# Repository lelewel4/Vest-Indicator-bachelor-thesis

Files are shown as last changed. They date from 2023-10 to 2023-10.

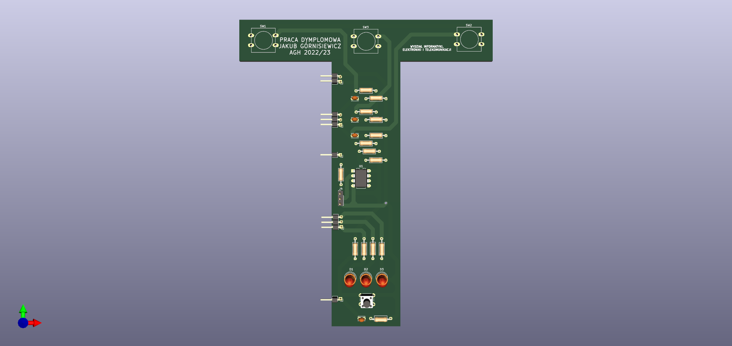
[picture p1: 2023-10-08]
PCB/Steering wheel/kierownica.png

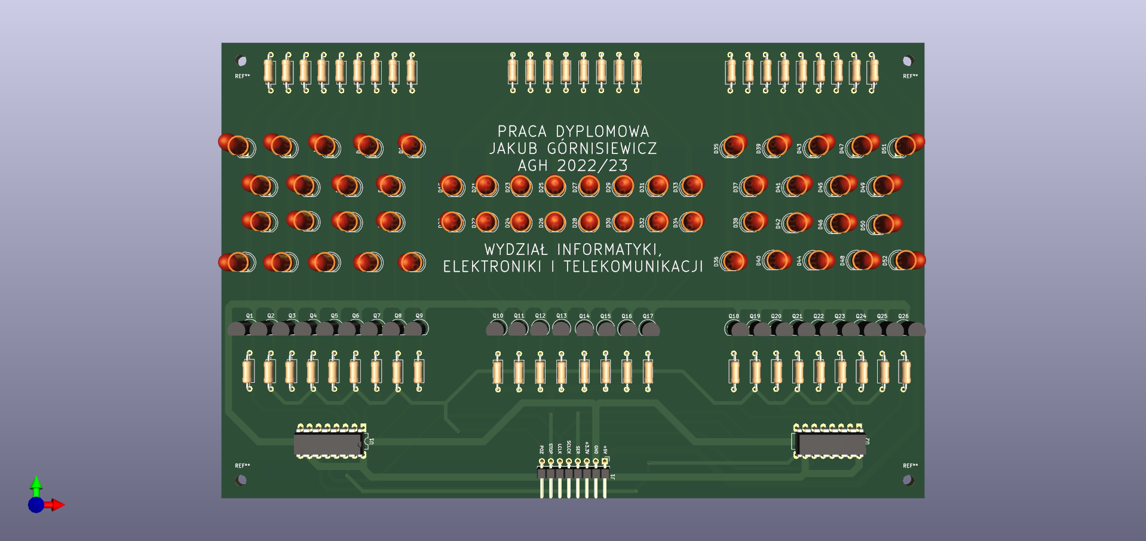
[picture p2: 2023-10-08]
PCB/Vest/kamizelka.png

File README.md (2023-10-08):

The engineering diploma thesis describes the design of a signal vest for an electric scooter driver based on wireless communication and STM32 microcontrollers.

The work contains a short introduction to the subject of e-scooters, after which the goal and scope of the project were defined. Existing commercial signal vest solutions were also reviewed. Then, the components enabling wireless communication were analyzed and development kits were selected. The entire project was divided into two parts: transmitting and receiving. Their appropriate functionality and requirements are outlined. Both parts discuss and justify the choice of specific electronic components. Electrical diagrams and printed circuits designed in KiCad are also presented. After this part, the PCBs were manufactured along with the assembly of elements. The subsections devoted to the software present the CubeMX environment, block diagrams, used libraries and interesting fragments of the source code written in C. Then, in the Tinkercad program, the appropriate housings were designed and manufactured in 3D technology. After assembling the project, functional tests were carried out.
The summary contains conclusions and further development directions for the project of a signaling vest for an electric scooter driver.

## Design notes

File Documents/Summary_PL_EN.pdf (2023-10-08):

W pracy inżynierskiej opisano projekt wykonanej kamizelki sygnalizacyjnej dla kierowcy hulajnogi elektrycznej w oparciu o komunikację bezprzewodową oraz mikrokontrolery STM32.

Praca zawiera krótki wstęp do tematyki e-hulajnóg, po którym określono cel i zakres projektu. Dokonano także przeglądu istniejących komercyjnych rozwiązań kamizelek sygnalizacyjnych. Następnie przeanalizowano komponenty umożliwiające komunikacje bezprzewodową oraz wybrano zestawy uruchomieniowe. Cały projekt podzielono na dwie części: nadawczą oraz odbiorczą. Nakreślono ich odpowiednią funkcjonalność oraz stawiane wymagania. W obu częściach omówiono i uzasadniono wybór konkretnych komponentów elektronicznych. Przedstawiono również zaprojektowane w programie KiCad schematy elektryczne oraz obwody drukowane. Po tej części dokonano wytworzenia płytek PCB wraz z montażem elementów. W podrozdziałach poświęconych oprogramowaniu zaprezentowano środowisko CubeMX, schematy blokowe, wykorzystane biblioteki oraz interesujące fragmenty kodu źródłowego napisanego w języku C. Następnie w programie Tinkercad zaprojektowano oraz wytworzono odpowiednie obudowy w technologii 3D. Po złożeniu projektu w całość przeprowadzono testy funkcjonalne.

W podsumowaniu zawarto wnioski oraz dalsze kierunki rozwoju projektu kamizelki sygnalizacyjnej dla kierowcy hulajnogi elektrycznej.

The engineering diploma thesis describes the design of a signal vest for an electric scooter driver based on wireless communication and STM32 microcontrollers.

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

The summary contains conclusions and further development directions for the project of a signaling vest for an electric scooter driver.

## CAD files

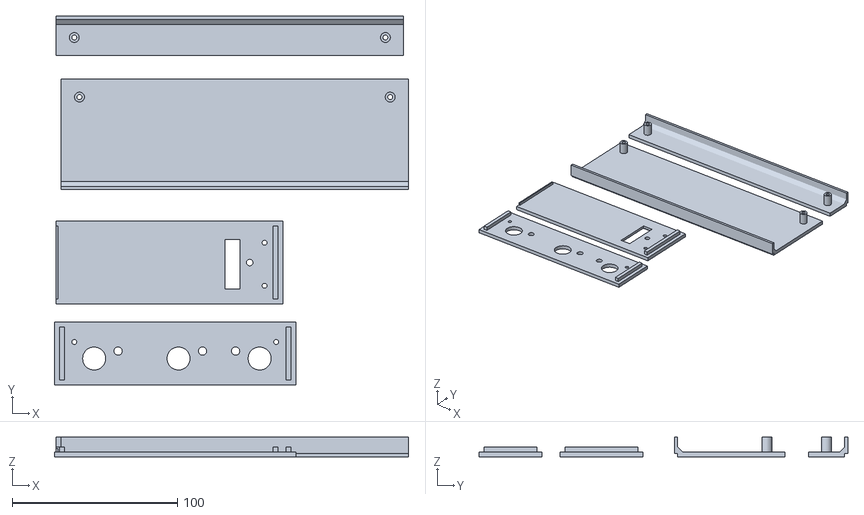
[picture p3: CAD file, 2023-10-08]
PRINT 3D/Fixing/tinker.obj
214.0 x 223.0 x 12.0

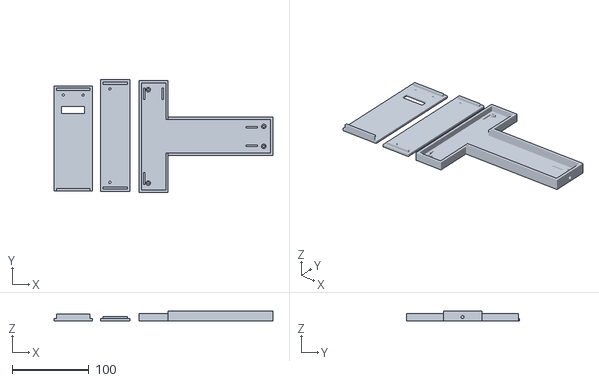
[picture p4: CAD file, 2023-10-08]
PRINT 3D/Steering wheel/Bottom and Top/tinker.obj
286.0 x 147.0 x 13.0

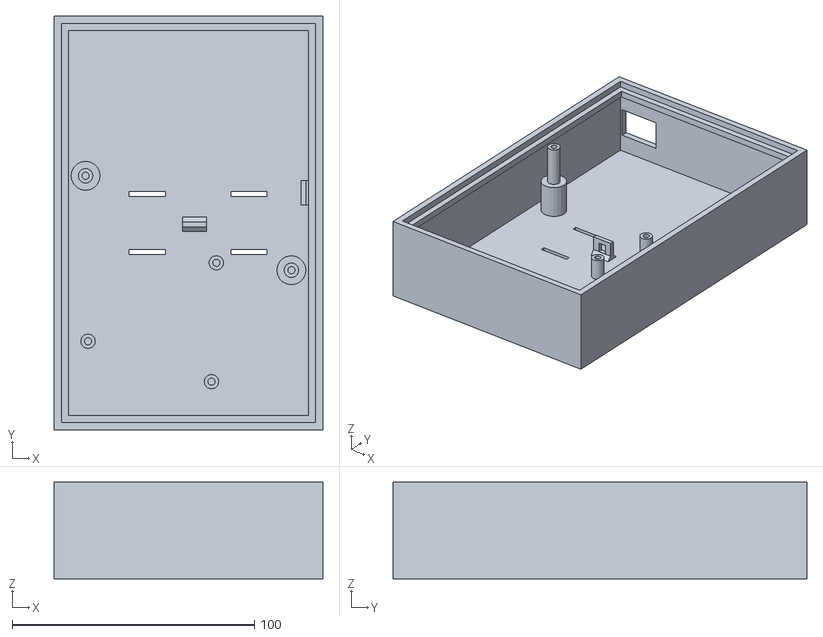
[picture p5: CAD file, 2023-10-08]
PRINT 3D/Supply/Bottom/tinker.obj
111.0 x 171.0 x 40.0

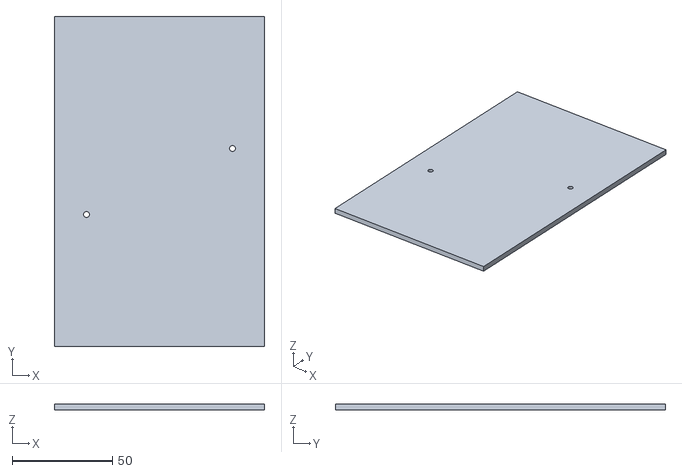
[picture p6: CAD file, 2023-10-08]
PRINT 3D/Supply/Top/tinker.obj
105.0 x 165.0 x 3.00

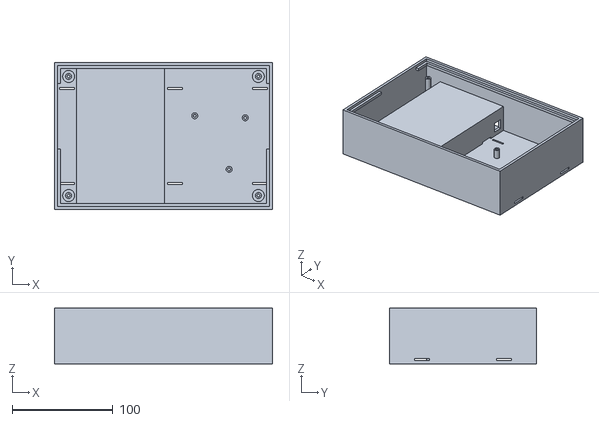
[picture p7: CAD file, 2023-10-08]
PRINT 3D/Vest/Bottom/tinker.obj
216.0 x 146.0 x 55.0

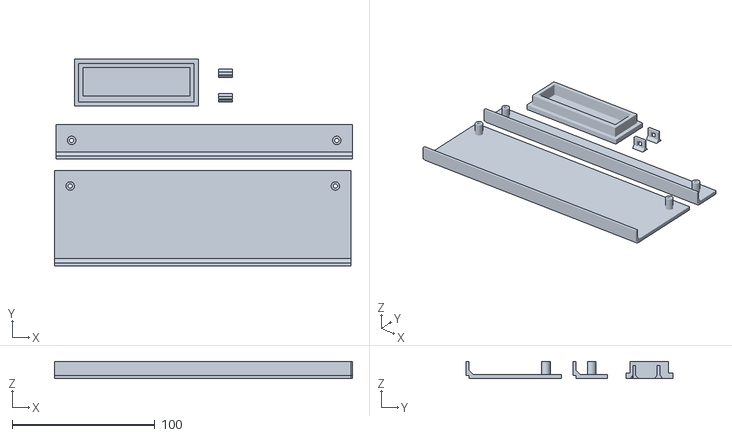
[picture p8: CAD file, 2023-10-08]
PRINT 3D/Vest/Top/tinker.obj
209.0 x 145.0 x 12.0

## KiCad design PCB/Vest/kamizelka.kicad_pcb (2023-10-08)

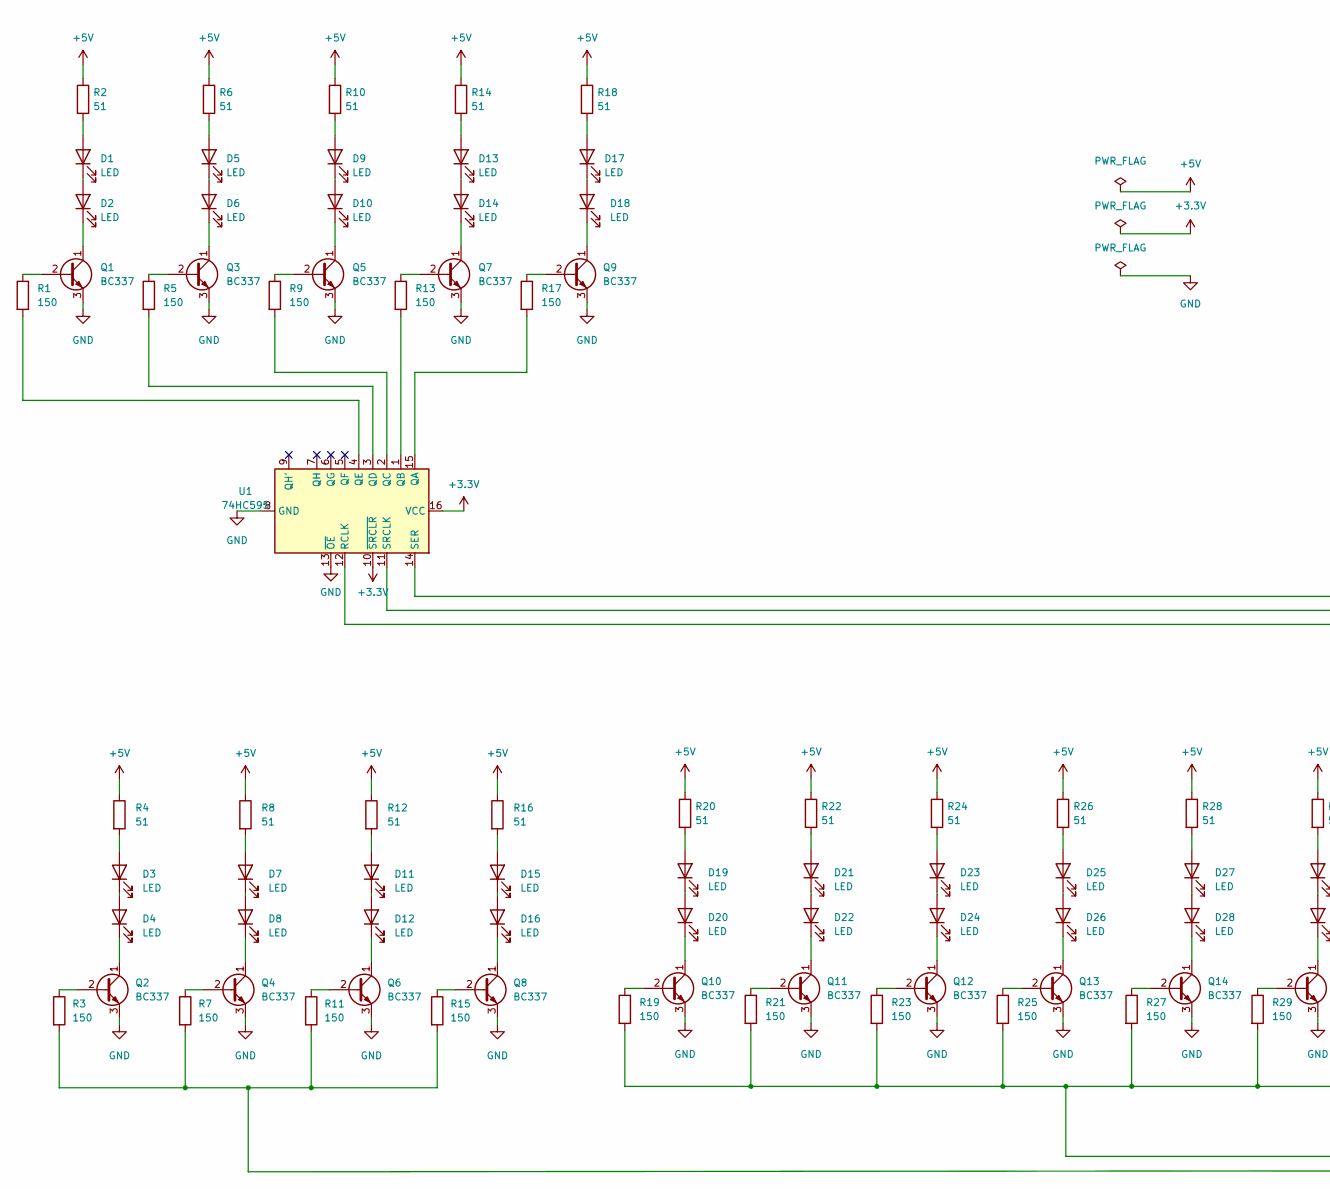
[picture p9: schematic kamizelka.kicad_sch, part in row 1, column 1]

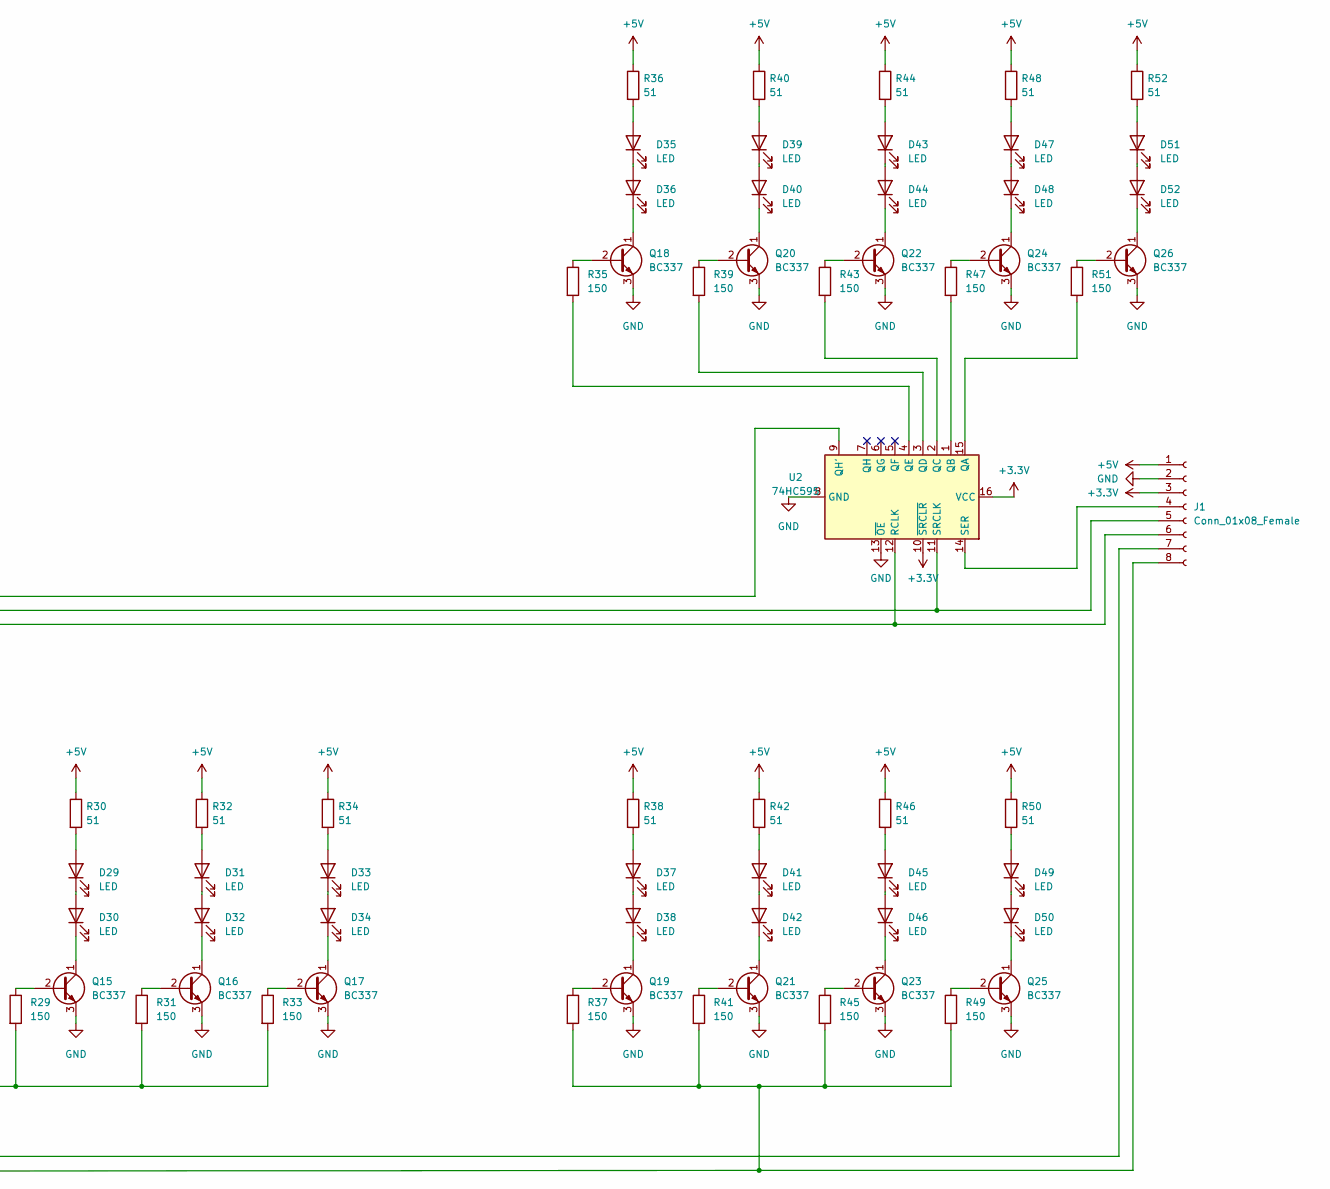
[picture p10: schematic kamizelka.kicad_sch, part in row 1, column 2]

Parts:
D1, D2, D3, D4, D5, D6, D7, D8, D9, D10, D11, D12, D13, D14, D15, D16, D17, D18, D19, D20, D21, D22, D23, D24, D25, D26, D27, D28, D29, D30, D31, D32, D33, D34, D35, D36, D37, D38, D39, D40, D41, D42, D43, D44, D45, D46, D47, D48, D49, D50, D51, D52: LED; LED_D5.0mm
J1: Conn_01x08_Female; PinHeader_1x08_P2.54mm_Horizontal
Q1, Q2, Q3, Q4, Q5, Q6, Q7, Q8, Q9, Q10, Q11, Q12, Q13, Q14, Q15, Q16, Q17, Q18, Q19, Q20, Q21, Q22, Q23, Q24, Q25, Q26: BC337; TO-92_Inline
R1, R3, R5, R7, R9, R11, R13, R15, R17, R19, R21, R23, R25, R27, R29, R31, R33, R35, R37, R39, R41, R43, R45, R47, R49, R51: 150; R_Axial_DIN0207_L6.3mm_D2.5mm_P10.16mm_Horizontal
R2, R4, R6, R8, R10, R12, R14, R16, R18, R20, R22, R24, R26, R28, R30, R32, R34, R36, R38, R40, R42, R44, R46, R48, R50, R52: 51; R_Axial_DIN0207_L6.3mm_D2.5mm_P10.16mm_Horizontal
U1, U2: 74HC595; DIP-16_W7.62mm_LongPads

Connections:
+3V3: J1.3, U1.10 (~SRCLR), U1.16 (VCC), U2.10 (~SRCLR), U2.16 (VCC)
+5V: J1.1, R2.1, R4.1, R6.1, R8.1, R10.1, R12.1, R14.1, R16.1, R18.1, R20.1, R22.1, R24.1, R26.1, R28.1, R30.1, R32.1, R34.1, R36.1, R38.1, R40.1, R42.1, R44.1, R46.1, R48.1, R50.1, R52.1
GND: J1.2, Q1.3 (E), Q2.3 (E), Q3.3 (E), Q4.3 (E), Q5.3 (E), Q6.3 (E), Q7.3 (E), Q8.3 (E), Q9.3 (E), Q10.3 (E), Q11.3 (E), Q12.3 (E), Q13.3 (E), Q14.3 (E), Q15.3 (E), Q16.3 (E), Q17.3 (E), Q18.3 (E), Q19.3 (E), Q20.3 (E), Q21.3 (E), Q22.3 (E), Q23.3 (E), Q24.3 (E), Q25.3 (E), Q26.3 (E), U1.8 (GND), U1.13 (~OE), U2.8 (GND), U2.13 (~OE)
unnamed: D1.1 (K), D2.2 (A)
unnamed: D1.2 (A), R2.2
unnamed: D2.1 (K), Q1.1 (C)
unnamed: D3.1 (K), D4.2 (A)
unnamed: D3.2 (A), R4.2
unnamed: D4.1 (K), Q2.1 (C)
unnamed: D5.1 (K), D6.2 (A)
unnamed: D5.2 (A), R6.2
unnamed: D6.1 (K), Q3.1 (C)
unnamed: D7.1 (K), D8.2 (A)
unnamed: D7.2 (A), R8.2
unnamed: D8.1 (K), Q4.1 (C)
unnamed: D9.1 (K), D10.2 (A)
unnamed: D9.2 (A), R10.2
unnamed: D10.1 (K), Q5.1 (C)
unnamed: D11.2 (A), R12.2
unnamed: D12.1 (K), Q6.1 (C)
unnamed: D11.1 (K), D12.2 (A)
unnamed: D13.1 (K), D14.2 (A)
unnamed: D13.2 (A), R14.2
unnamed: D14.1 (K), Q7.1 (C)
unnamed: D15.1 (K), D16.2 (A)
unnamed: D15.2 (A), R16.2
unnamed: D16.1 (K), Q8.1 (C)
unnamed: D17.1 (K), D18.2 (A)
unnamed: D17.2 (A), R18.2
unnamed: D18.1 (K), Q9.1 (C)
unnamed: D19.1 (K), D20.2 (A)
unnamed: D19.2 (A), R20.2
unnamed: D20.1 (K), Q10.1 (C)
unnamed: D21.1 (K), D22.2 (A)
unnamed: D21.2 (A), R22.2
unnamed: D22.1 (K), Q11.1 (C)
unnamed: D23.1 (K), D24.2 (A)
unnamed: D23.2 (A), R24.2
unnamed: D24.1 (K), Q12.1 (C)
unnamed: D25.1 (K), D26.2 (A)
unnamed: D25.2 (A), R26.2
unnamed: D26.1 (K), Q13.1 (C)
unnamed: D27.1 (K), D28.2 (A)
unnamed: D27.2 (A), R28.2
unnamed: D28.1 (K), Q14.1 (C)
unnamed: D29.1 (K), D30.2 (A)
unnamed: D29.2 (A), R30.2
unnamed: D30.1 (K), Q15.1 (C)
unnamed: D31.1 (K), D32.2 (A)
unnamed: D31.2 (A), R32.2
unnamed: D32.1 (K), Q16.1 (C)
unnamed: D33.1 (K), D34.2 (A)
unnamed: D33.2 (A), R34.2
unnamed: D34.1 (K), Q17.1 (C)
unnamed: D35.1 (K), D36.2 (A)
unnamed: D35.2 (A), R36.2
unnamed: D36.1 (K), Q18.1 (C)
unnamed: D37.1 (K), D38.2 (A)
unnamed: D37.2 (A), R38.2
unnamed: D38.1 (K), Q19.1 (C)
unnamed: D39.1 (K), D40.2 (A)
unnamed: D39.2 (A), R40.2
unnamed: D40.1 (K), Q20.1 (C)
unnamed: D41.1 (K), D42.2 (A)
unnamed: D41.2 (A), R42.2
unnamed: D42.1 (K), Q21.1 (C)
unnamed: D43.1 (K), D44.2 (A)
unnamed: D43.2 (A), R44.2
unnamed: D44.1 (K), Q22.1 (C)
unnamed: D45.1 (K), D46.2 (A)
unnamed: D45.2 (A), R46.2
unnamed: D46.1 (K), Q23.1 (C)
unnamed: D47.1 (K), D48.2 (A)
unnamed: D47.2 (A), R48.2
unnamed: D48.1 (K), Q24.1 (C)
unnamed: D49.1 (K), D50.2 (A)
unnamed: D49.2 (A), R50.2
unnamed: D50.1 (K), Q25.1 (C)
unnamed: D51.1 (K), D52.2 (A)
unnamed: D51.2 (A), R52.2
unnamed: D52.1 (K), Q26.1 (C)
unnamed: J1.4, U2.14 (SER)
unnamed: J1.5, U1.11 (SRCLK), U2.11 (SRCLK)
unnamed: J1.6, U1.12 (RCLK), U2.12 (RCLK)
unnamed: J1.7, R19.2, R21.2, R23.2, R25.2, R27.2, R29.2, R31.2, R33.2
unnamed: J1.8, R3.2, R7.2, R11.2, R15.2, R37.2, R41.2, R45.2, R49.2
unnamed: Q1.2 (B), R1.1
unnamed: Q2.2 (B), R3.1
unnamed: Q3.2 (B), R5.1
unnamed: Q4.2 (B), R7.1
unnamed: Q5.2 (B), R9.1
unnamed: Q6.2 (B), R11.1
unnamed: Q7.2 (B), R13.1
unnamed: Q8.2 (B), R15.1
unnamed: Q9.2 (B), R17.1
unnamed: Q10.2 (B), R19.1
unnamed: Q11.2 (B), R21.1
unnamed: Q12.2 (B), R23.1
unnamed: Q13.2 (B), R25.1
unnamed: Q14.2 (B), R27.1
unnamed: Q15.2 (B), R29.1
unnamed: Q16.2 (B), R31.1
unnamed: Q17.2 (B), R33.1
unnamed: Q18.2 (B), R35.1
unnamed: Q19.2 (B), R37.1
unnamed: Q20.2 (B), R39.1
unnamed: Q21.2 (B), R41.1
unnamed: Q22.2 (B), R43.1
unnamed: Q23.2 (B), R45.1
unnamed: Q24.2 (B), R47.1
unnamed: Q25.2 (B), R49.1
unnamed: Q26.2 (B), R51.1
unnamed: R1.2, U1.4 (QE)
unnamed: R5.2, U1.3 (QD)
unnamed: R9.2, U1.2 (QC)
unnamed: R13.2, U1.1 (QB)
unnamed: R17.2, U1.15 (QA)
unnamed: R35.2, U2.4 (QE)
unnamed: R39.2, U2.3 (QD)
unnamed: R43.2, U2.2 (QC)
unnamed: R47.2, U2.1 (QB)
unnamed: R51.2, U2.15 (QA)
unnamed: U1.14 (SER), U2.9 (QH')

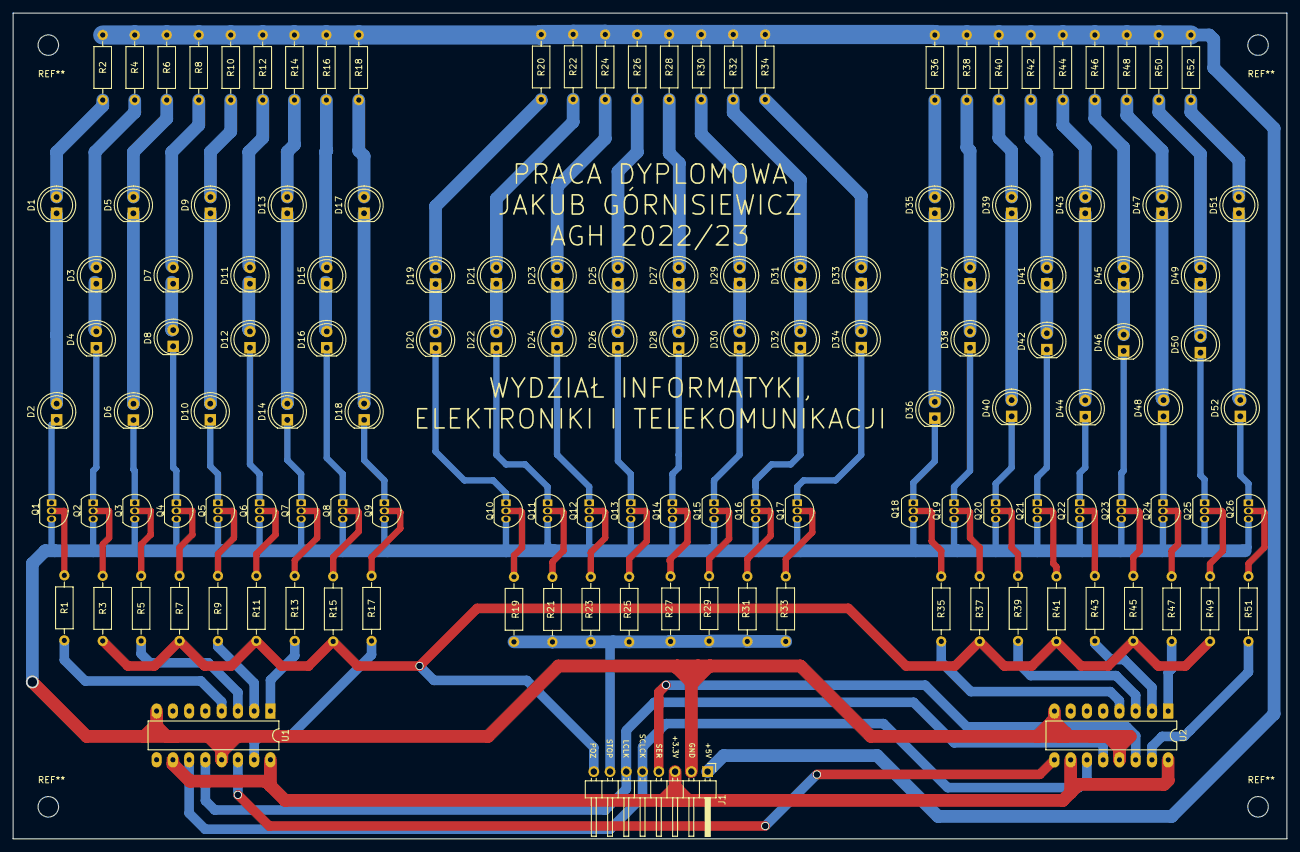
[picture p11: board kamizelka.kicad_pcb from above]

Board: 2 copper layers, 199.0 x 129.0 mm, 133 parts (0 on the bottom side), 123 nets.

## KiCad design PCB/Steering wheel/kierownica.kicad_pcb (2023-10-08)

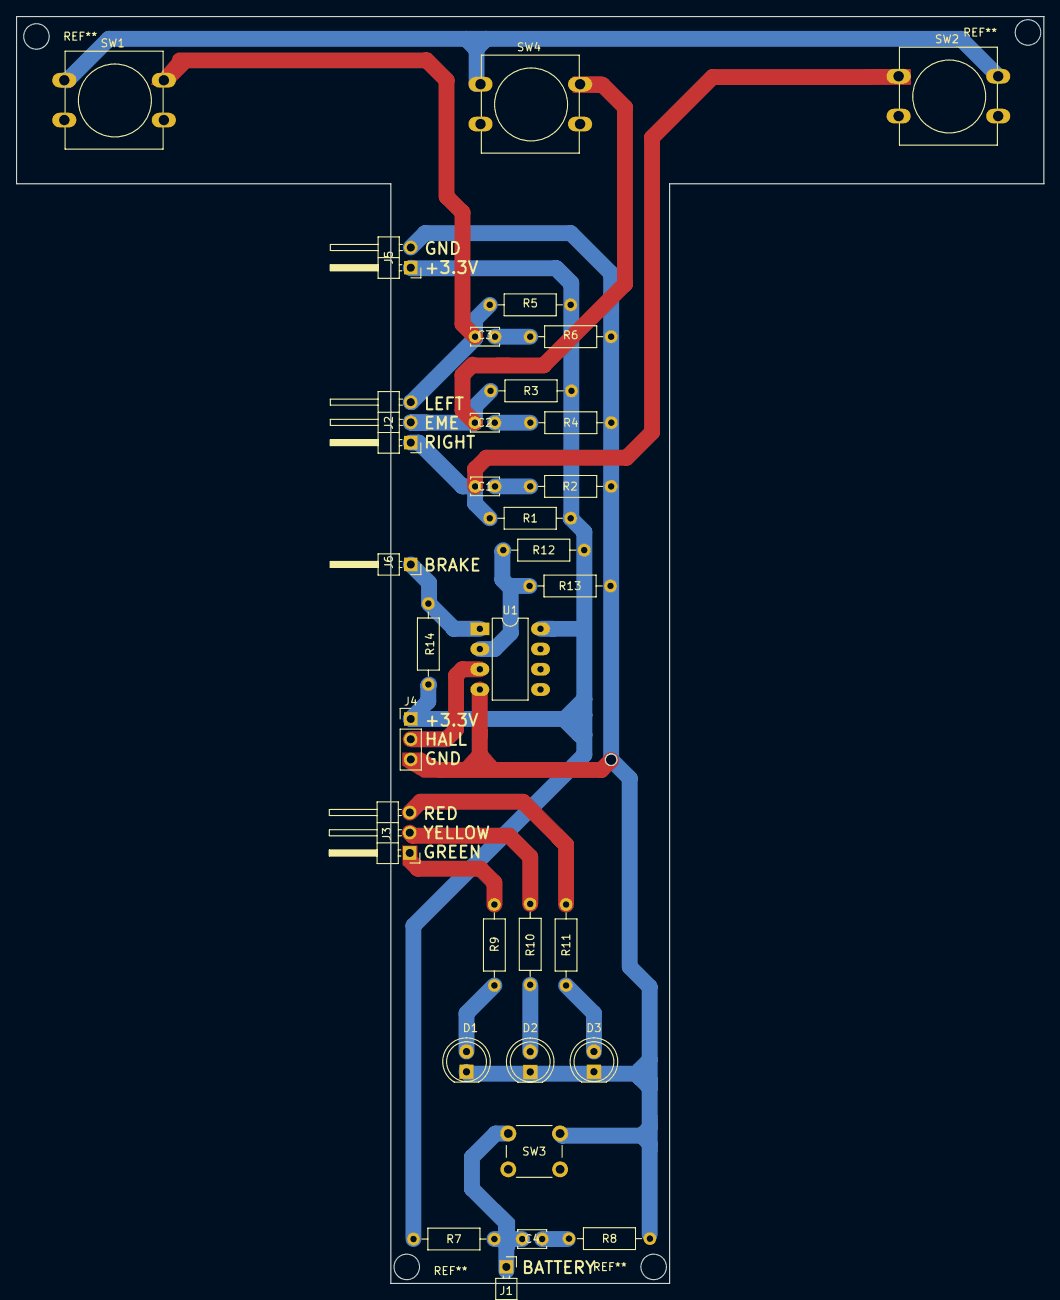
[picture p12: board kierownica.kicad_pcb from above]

Board: 2 copper layers, 129.0 x 159.1 mm, 32 parts (0 on the bottom side), 19 nets.

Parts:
C1, C2, C3, C4: 100n; C_Disc_D3.4mm_W2.1mm_P2.50mm
D1: LED_RED; LED_D5.0mm
D2: LED_YELLOW; LED_D5.0mm
D3: LED_GREEN; LED_D5.0mm
J1, J6: Conn_01x01_Female; PinHeader_1x01_P2.54mm_Horizontal
J2, J3: Conn_01x03_Female; PinHeader_1x03_P2.54mm_Horizontal
J4: Conn_01x03_Female; PinHeader_1x03_P2.54mm_Vertical
J5: Conn_01x02_Female; PinHeader_1x02_P2.54mm_Horizontal
R1, R3, R5, R7: 4.7k; R_Axial_DIN0207_L6.3mm_D2.5mm_P10.16mm_Horizontal
R2, R4, R6, R8: 100; R_Axial_DIN0207_L6.3mm_D2.5mm_P10.16mm_Horizontal
R9, R10, R11: 76,4; R_Axial_DIN0207_L6.3mm_D2.5mm_P10.16mm_Horizontal
R12: 330; R_Axial_DIN0207_L6.3mm_D2.5mm_P10.16mm_Horizontal
R13: 130; R_Axial_DIN0207_L6.3mm_D2.5mm_P10.16mm_Horizontal
R14: 4,7k; R_Axial_DIN0207_L6.3mm_D2.5mm_P10.16mm_Horizontal
SW1: SW_LEFT; SW_PUSH-12mm
SW2: SW_RIGHT; SW_PUSH-12mm
SW3: SW_BATTERY; SW_PUSH_6mm_H7.3mm
SW4: SW_EMERGENCY; SW_PUSH-12mm
U1: LM393; DIP-8_W7.62mm_LongPads

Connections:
+3V3: J4.1, J5.1, R1.2, R3.2, R5.2, R7.2, R12.1, R14.1
GND: D1.1 (K), D2.1 (K), D3.1 (K), J4.3, J5.2, R2.2, R4.2, R6.2, R8.2, R13.2, SW1.1, SW2.1, SW3.1, SW4.1
unnamed: C1.1, J2.1, R1.1
unnamed: C1.2, R2.1
unnamed: C2.1, J2.2, R3.1
unnamed: C2.2, R4.1
unnamed: C3.1, J2.3, R5.1
unnamed: C3.2, R6.1
unnamed: C4.1, J1.1, R7.1
unnamed: C4.2, R8.1
unnamed: D1.2 (A), R9.2
unnamed: D2.2 (A), R10.2
unnamed: D3.2 (A), R11.2
unnamed: J3.1, R9.1
unnamed: J3.2, R10.1
unnamed: J3.3, R11.1
unnamed: J4.2, U1.3 (+)
unnamed: J6.1, R14.2, U1.1
unnamed: R12.2, R13.1, U1.2 (-)

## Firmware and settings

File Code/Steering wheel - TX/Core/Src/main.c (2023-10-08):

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
/* Includes ------------------------------------------------------------------*/
#include "main.h"
#include "adc.h"
#include "spi.h"
#include "usart.h"
#include "gpio.h"

/* USER CODE BEGIN Includes */
#include "stdio.h"
#include "nRF24_Defs.h"
#include "nRF24.h"
#include "light_functions.h"
#include "ADC_functions.h"
/* USER CODE END Includes */


/* USER CODE BEGIN PV */


//UART///
int __io_putchar(int ch){
  if (ch == '\n') {
    __io_putchar('\r');
  }
  HAL_UART_Transmit(&huart2, (uint8_t*)&ch, 1, HAL_MAX_DELAY);
  return 1;
}


//GPIO IRQ//
void HAL_GPIO_EXTI_Callback(uint16_t GPIO_Pin)
{
    current_time = HAL_GetTick();		//time reading
    //button battery
    if((GPIO_Pin == BB_Pin) && (current_time - previous_time)>BUTTON_DEBOUNCE_TIME)
    {
        light = LIGHT_BATTERY;
    }
    //button stop
    if((GPIO_Pin == BS_Pin) && (current_time - previous_time)>STOP_DEBOUNCE_TIME)
    {
        light = LIGHT_STOP;
    }
    //button emergency
    if((GPIO_Pin == BE_Pin) && (current_time - previous_time)>BUTTON_DEBOUNCE_TIME)
    {
    	emergency_button_value = !emergency_button_value;		//toggle of value
        light = LIGHT_EMERGENCY;
    }
    //button left
    if((GPIO_Pin == BL_Pin) && (current_time - previous_time)>BUTTON_DEBOUNCE_TIME)
    {
    	left_button_value = !left_button_value;					//toggle of value
        light = LIGHT_LEFT;
    }
    //button right
    if((GPIO_Pin == BR_Pin) && (current_time - previous_time)>BUTTON_DEBOUNCE_TIME)
    {
        right_button_value = !right_button_value;				//toggle of value
        light = LIGHT_RIGHT;
    }
    previous_time = current_time;						//previous time assignment
}


/* USER CODE END PV */

void SystemClock_Config(void);
/**
  * @brief  The application entry point.
  * @retval int
  */
int main(void)
{
  /* MCU Configuration--------------------------------------------------------*/

  /* Reset of all peripherals, Initializes the Flash interface and the Systick. */
  HAL_Init();

  /* Configure the system clock */
  SystemClock_Config();

  /* Initialize all configured peripherals */
  MX_GPIO_Init();
  MX_USART2_UART_Init();
  MX_SPI1_Init();
  MX_ADC1_Init();
  MX_SPI2_Init();
  /* USER CODE BEGIN 2 */

  nRF24_Init(&hspi1);
  nRF24_SetRXAddress(0, "Nad");
  nRF24_SetTXAddress("Odb");
  nRF24_TX_Mode();

  /* USER CODE END 2 */

  /* Infinite loop */
  /* USER CODE BEGIN WHILE */
  while (1)
  {
      switch(light)
      {
      //battery
      case LIGHT_BATTERY:
    	  adc_value = get_adc_battery_value();
          battery_level_show(adc_value);
          light = LIGHT_INIT;				//default value
          break;
      //stop
      case LIGHT_STOP:
    	  stop_light_logic();
    	  light = LIGHT_INIT;
    	  break;
      //emergency
      case LIGHT_EMERGENCY:
    	  emergency_light_logic();
    	  light = LIGHT_INIT;
    	  break;
      //left turn
      case LIGHT_LEFT:
    	  left_light_logic();
    	  light = LIGHT_INIT;
    	  break;
      //right turn
      case LIGHT_RIGHT:
    	  right_light_logic();
    	  light = LIGHT_INIT;
    	  break;
      //empty (do nothing)
      case LIGHT_INIT:
    	  while(light == LIGHT_INIT){
    		  __NOP();						//do nothing
    	  }
    	  break;
      }

    /* USER CODE END WHILE */

    /* USER CODE BEGIN 3 */
  }
  /* USER CODE END 3 */
}

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


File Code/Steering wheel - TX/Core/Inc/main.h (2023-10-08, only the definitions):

#define SPI2_LATCH_Pin GPIO_PIN_2
#define SPI2_LATCH_GPIO_Port GPIOC
#define USART_TX_Pin GPIO_PIN_2
#define USART_TX_GPIO_Port GPIOA
#define USART_RX_Pin GPIO_PIN_3
#define USART_RX_GPIO_Port GPIOA
#define TL_Pin GPIO_PIN_5
#define TL_GPIO_Port GPIOC
#define BS_Pin GPIO_PIN_12
#define BS_GPIO_Port GPIOB
#define BS_EXTI_IRQn EXTI15_10_IRQn
#define BB_Pin GPIO_PIN_13
#define BB_GPIO_Port GPIOB
#define BB_EXTI_IRQn EXTI15_10_IRQn
#define BL_Pin GPIO_PIN_14
#define BL_GPIO_Port GPIOB
#define BL_EXTI_IRQn EXTI15_10_IRQn
#define BR_Pin GPIO_PIN_15
#define BR_GPIO_Port GPIOB
#define BR_EXTI_IRQn EXTI15_10_IRQn
#define DE_Pin GPIO_PIN_6
#define DE_GPIO_Port GPIOC
#define NRF24_CSN_Pin GPIO_PIN_7
#define NRF24_CSN_GPIO_Port GPIOC
#define TR_Pin GPIO_PIN_8
#define TR_GPIO_Port GPIOC
#define BE_Pin GPIO_PIN_9
#define BE_GPIO_Port GPIOC
#define BE_EXTI_IRQn EXTI9_5_IRQn
#define DG_Pin GPIO_PIN_10
#define DG_GPIO_Port GPIOA
#define TMS_Pin GPIO_PIN_13
#define TMS_GPIO_Port GPIOA
#define TCK_Pin GPIO_PIN_14
#define TCK_GPIO_Port GPIOA
#define SWO_Pin GPIO_PIN_3
#define SWO_GPIO_Port GPIOB
#define DY_Pin GPIO_PIN_4
#define DY_GPIO_Port GPIOB
#define DR_Pin GPIO_PIN_5
#define DR_GPIO_Port GPIOB
#define NRF24_CE_Pin GPIO_PIN_6
#define NRF24_CE_GPIO_Port GPIOB

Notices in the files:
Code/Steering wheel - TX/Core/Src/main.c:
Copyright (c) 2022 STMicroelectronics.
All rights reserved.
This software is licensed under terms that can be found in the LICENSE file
